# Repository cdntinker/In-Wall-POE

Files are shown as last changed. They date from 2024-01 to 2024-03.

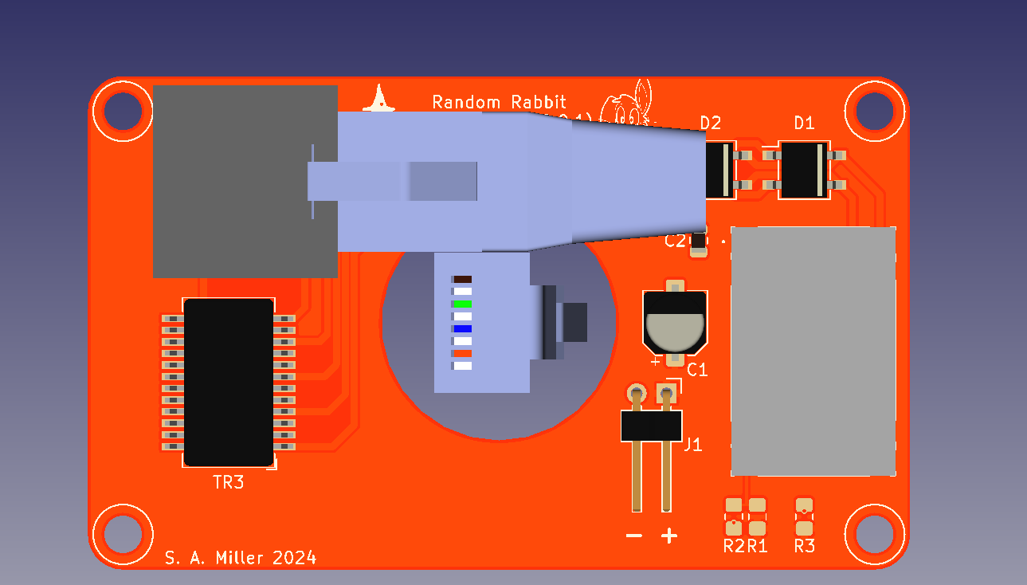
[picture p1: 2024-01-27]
3D/PoE top.png

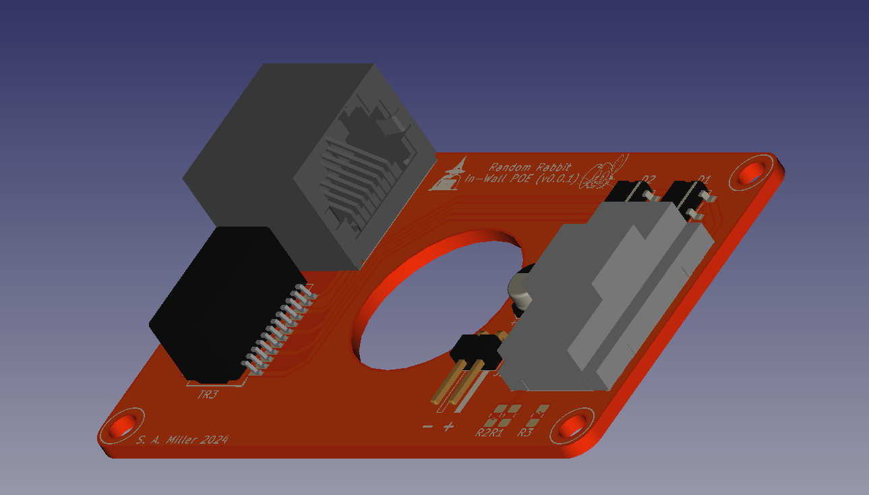
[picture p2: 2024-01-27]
3D/PoE.png

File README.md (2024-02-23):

Designed to fit inside of Wiremold surface mount boxes.

Inspired by the EAP235-wall wireless access point which has pass-through PoE.  I have a little receiver for my weather station that connects to the network via WiFi & is powered by a USB charger.

Center hole, initially,  exists to make room for the Ethernet cable feeding the EAP235.  Of course, it can also allow for the cables to feed into the wall.

J1 supplies 5V output at up to 7W and can have a USB-A pigtail connected to feed devices outside the box.

The outline on layer User1 is the internals of a typical Wiremold surface box.

> [!NOTE]
> The outline on layer User2 in the board view is a fairly accurate representation of an Ethernet plug in position in the jack.
> 
> The outline on layer User3 is a fairly accurate representation of an Ethernet plug in the back of the EAP235.

> [!TIP]
> Actual board should fit in ANY North American box.

> [!TIP]
> The PoE module in use is available in 3v3, 5v0 and 12v versions.
> So, this board could also be used to supply those voltages.

> [!NOTE]
> See notations in the schematic and refer to the datasheet for information about resistors R1-R3.

2024/01/22: upgraded from the overkill Ethernet jack to a better fit plus magnetics...

2024/02/13: Assembled first board
* No smoke, but not producing output properly...
  * So far, suspect it needs more of a load.  Will test once I find a USB-A pigtail.
* Need to change footprint of L1 to something easier to hand-solder & move C1 a little to the left to make assembly easier.

2024/02/15: Tested successfully
* Definitely needs minimum load.
  * Added 2x 470 ohm resistors in parallel at R3 (Now Rl1 & Rl2)
* ~~Does not seem to reliably keep voltage under much load.~~
  * ~~Possibly because of knock-off module?  Must get Silvertel modules & test...~~
* Modified L1 footprint, moved C1 & added an extra load resistor footprint.  All to ease assembly.

2024/02/22: Tested with actual Silvertel module AND no longer trust Chinese USB testers
* Received Silvertel module from Mouser & assembled another board.
  * EXACTLY the same results.
* **THEN**, Just for giggles, actually measured the output with my regular meter (Uni-T UT61e)
  * Well...  That's interesting.  UT61e says the output is a nice stable 5V (give or take ~0.03V)
  * Yet the load tester AND an inline USB tester both show severe voltage drop as current goes up.

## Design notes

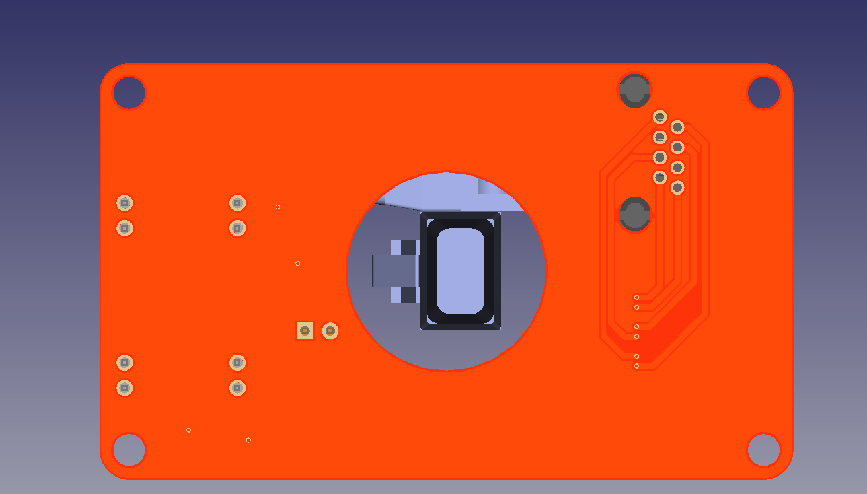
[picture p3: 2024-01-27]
3D/PoE bottom.png

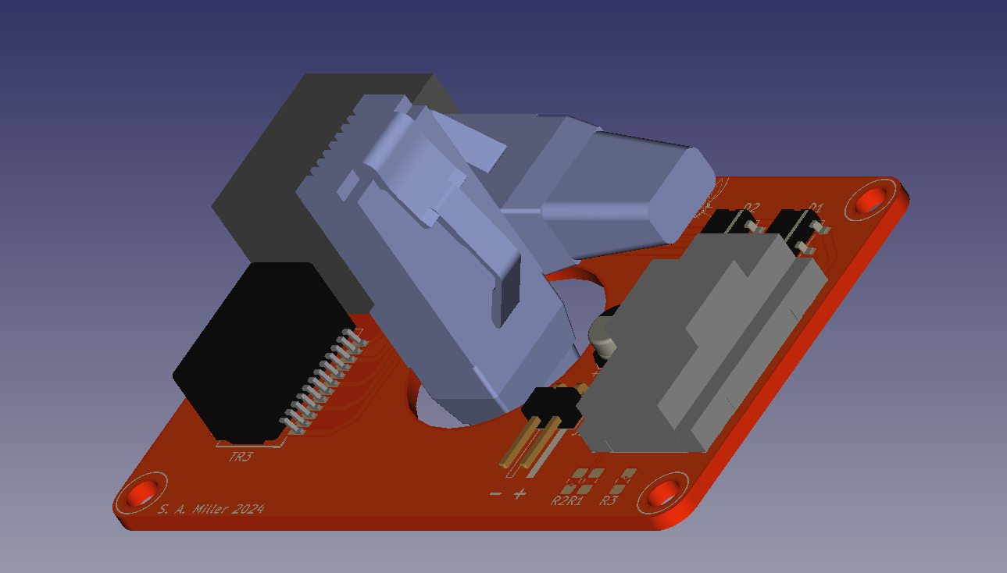
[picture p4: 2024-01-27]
3D/PoE Connected + WAP.png

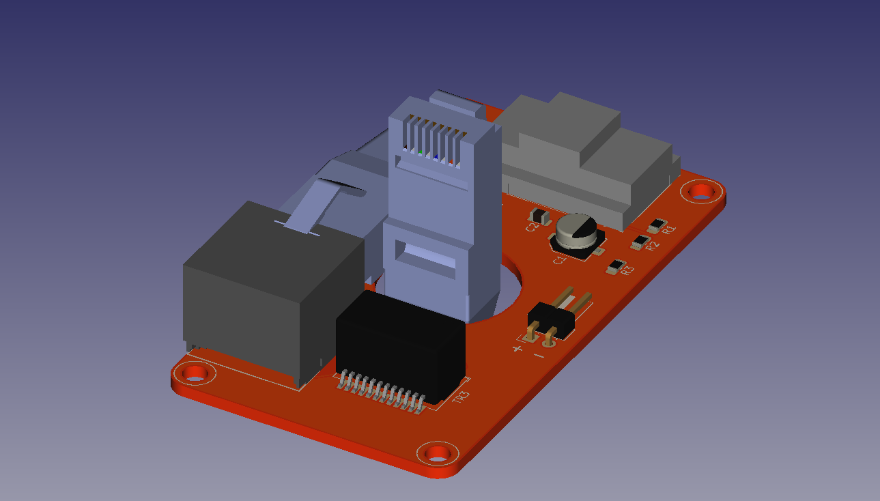
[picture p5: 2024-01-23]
3D/In Use.png

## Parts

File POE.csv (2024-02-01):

Component Count: | 16
Ref | Qnty | Cmp name | Value | LCSC | DigiKey | Footprint | Description
C1, | 1 | C_Polarized | 100uf | C7442639 |  | Capacitor_SMD:CP_Elec_6.3x5.4 | Polarized capacitor
C2, C3, | 2 | C | 10uf | C15850 |  | Capacitor_SMD:C_0805_2012Metric | Unpolarized capacitor
D1, D2, | 2 | MB4S | MB4S | C20612967 |  | Package_TO_SOT_SMD:TO-269AA | Miniature Glass Passivated Single-Phase Surface Mount Bridge Rectifiers, 280V Vrms, 0.5A If, TO-269AA
D3, | 1 | Z1SMAxxx | SMAJ58A | C280379 |  | Diode_SMD:D_SMA | 1000mW Zener Diode, SMA(DO-214AC)
D4, | 1 | LED | LED |  |  | LED_SMD:LED_0805_2012Metric | Light emitting diode
J1, | 1 | RC01374 | RC01374 | C385834 |  | tightstuff:RC01374
J2, | 1 | Conn_01x02_Male | Conn_01x02_Male |  |  | Connector_PinHeader_2.54mm:PinHeader_1x02_P2.54mm_Horizontal | Generic connector, single row, 01x02, script generated (kicad-library-utils/schlib/autogen/connector/)
L1, | 1 | L_Iron | fnr3015s1r | C167746 |  | tightstuff:fnr3015s | Inductor with iron core
MOD-1, | 1 | Ag9912LP | Ag9905LP | C5380108 |  | Tinker:Ag9912LP | Power over Ethernet - PoE IEEE802.3af PD module. 12V 10W low profile
R1, R2, R4, | 3 | R | ? |  |  | Resistor_SMD:R_0805_2012Metric_Pad1.20x1.40mm_HandSolder | Resistor
R3, | 1 | R | Rmin |  |  | Resistor_SMD:R_0805_2012Metric_Pad1.20x1.40mm_HandSolder | Resistor
TR3, | 1 | TG111-MSC13LF | SET2401ST | C7603464 |  | tightstuff:Eth_Magnetics (1.0) | Single Port Gigabit Ethernet Transformers

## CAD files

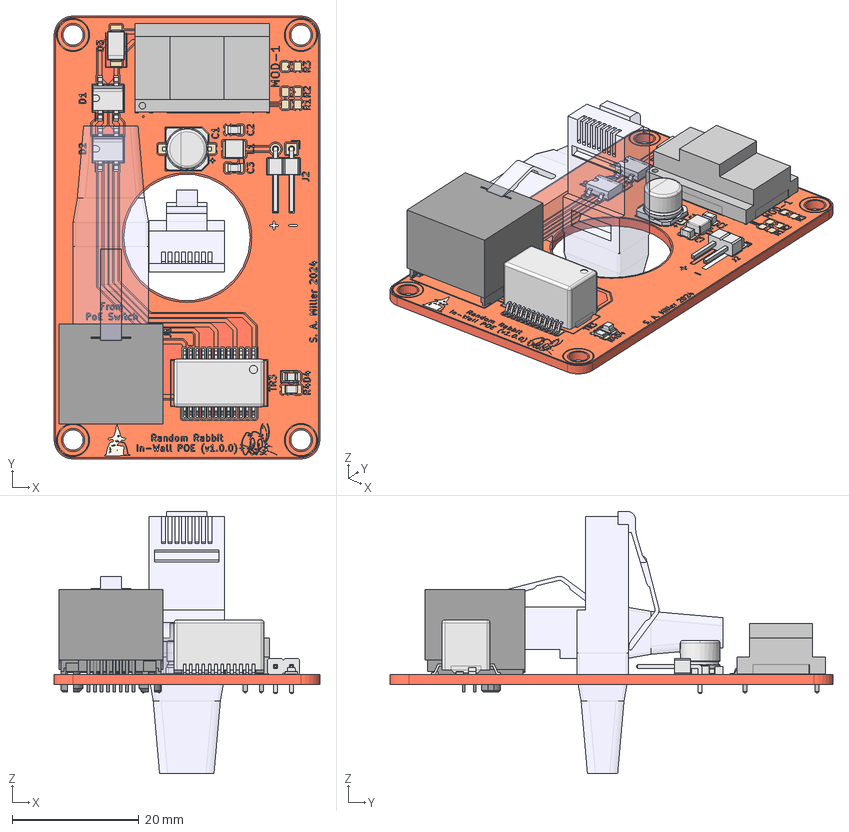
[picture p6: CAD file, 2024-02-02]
3D/PoE.FCStd
42.0 x 70.0 x 41.4 mm
Ethernet Male (in)
Ethernet Male
Pcb_5b5d001
topPads_5b5d001
topTracks_5b5d001
topZones_5b5d001
botPads_5b5d001
botTracks_5b5d001
botZones_5b5d001
topSilks_8e019
J1_RC01374_910414891cc3
D2_TO-269AA_a9b336d096a008 x 2
J2_PinHeader_1x02_P254mm_Horizontal_e8eeef0b0424
C1_CP_Elec_63x54_8ff1b6274a91
R4_R_0805_2012Metric_b68a1f3f8587
D3_D_SMA_5c7a696e1d8e001
MOD-1_Pocket_6c58673b8a2c001
C3_C_0805_2012Metric_1d8ab9cbe80f x 2
Transformer_Ethernet_HALO_TG111-MSC026
Transformer_Ethernet_HALO_TG111-MSC027
Transformer_Ethernet_HALO_TG111-MSC028
Transformer_Ethernet_HALO_TG111-MSC029
Transformer_Ethernet_HALO_TG111-MSC030
Transformer_Ethernet_HALO_TG111-MSC031
Transformer_Ethernet_HALO_TG111-MSC032
Transformer_Ethernet_HALO_TG111-MSC033
Transformer_Ethernet_HALO_TG111-MSC034
Transformer_Ethernet_HALO_TG111-MSC035
Transformer_Ethernet_HALO_TG111-MSC036
Transformer_Ethernet_HALO_TG111-MSC037
Transformer_Ethernet_HALO_TG111-MSC038
D4_LED_0805_2012Metric_7e3a714fea2e
L1_L_Wuerth_MAPI_3015_82f39c7c552b

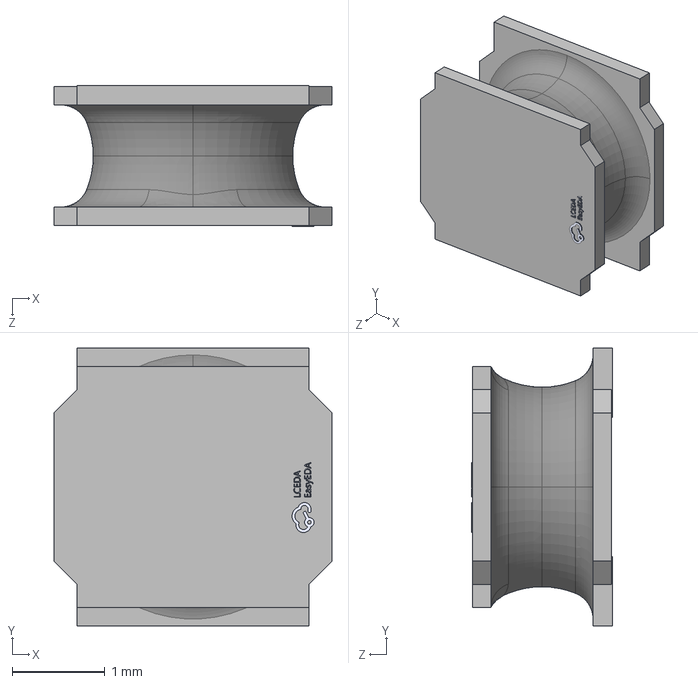
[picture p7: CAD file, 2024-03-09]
KiCAD Customs/3D/IND-SMD_L3.0-W3.0-H1.5_FNR30XXS.step
3.00 x 3.00 x 1.52 mm

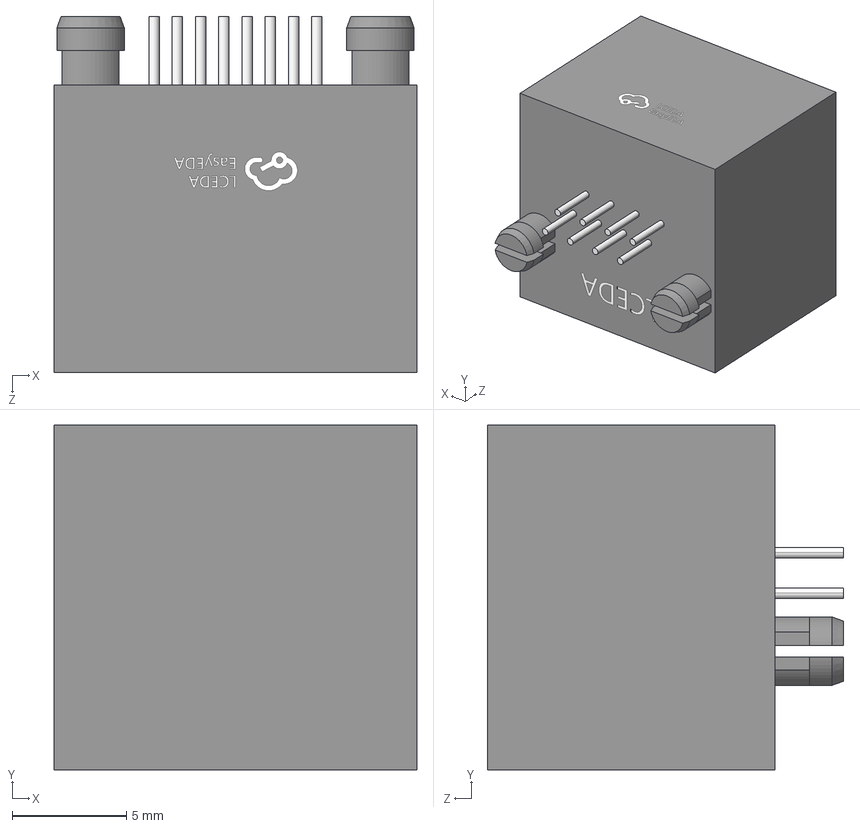
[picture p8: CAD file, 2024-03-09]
KiCAD Customs/3D/RJ45-TH_L15.9-W15.1-H12.6.step
15.9 x 15.1 x 15.6 mm

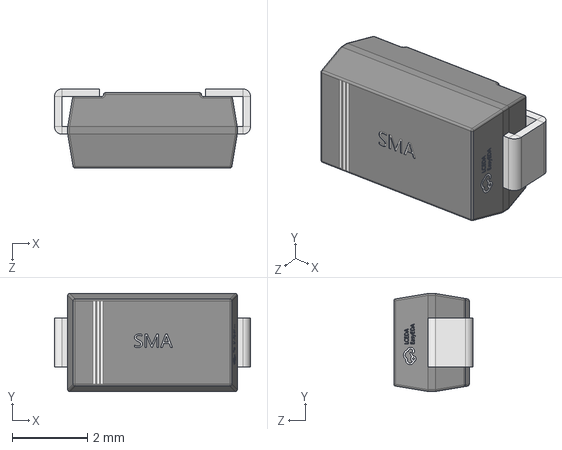
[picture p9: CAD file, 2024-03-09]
KiCAD Customs/3D/SMA_L4.4-W2.8-LS5.4-RD.step
5.20 x 2.60 x 2.10 mm

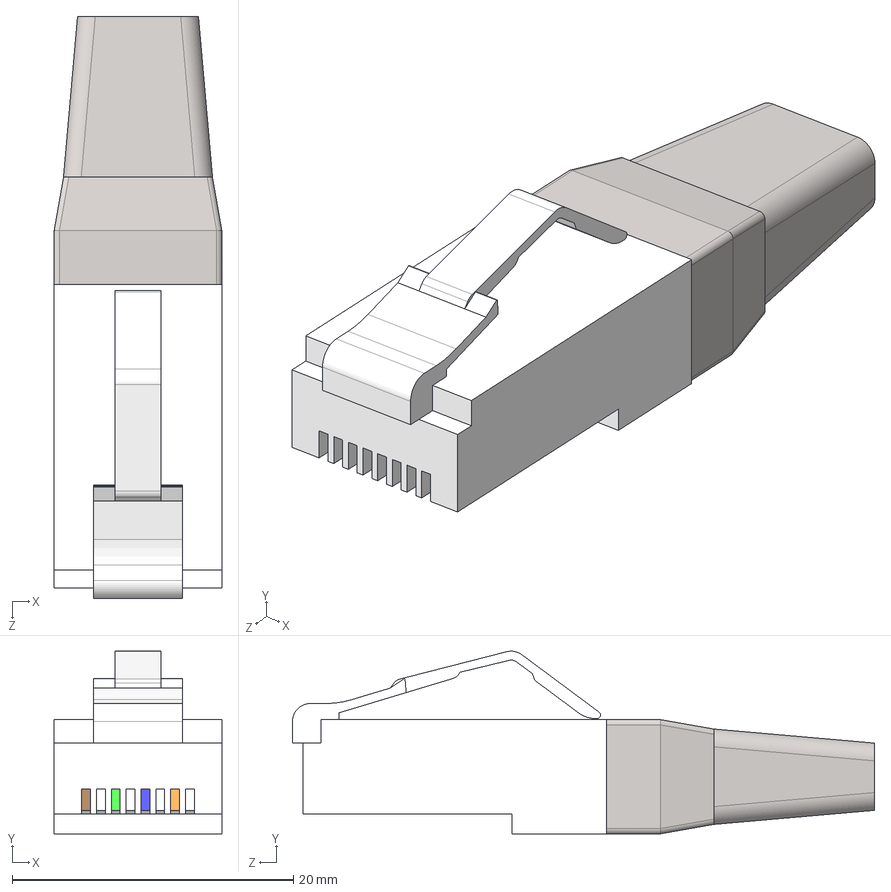
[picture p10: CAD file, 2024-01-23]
KiCAD Customs/3D/Ethernet Male.STEP
11.9 x 13.0 x 41.4 mm

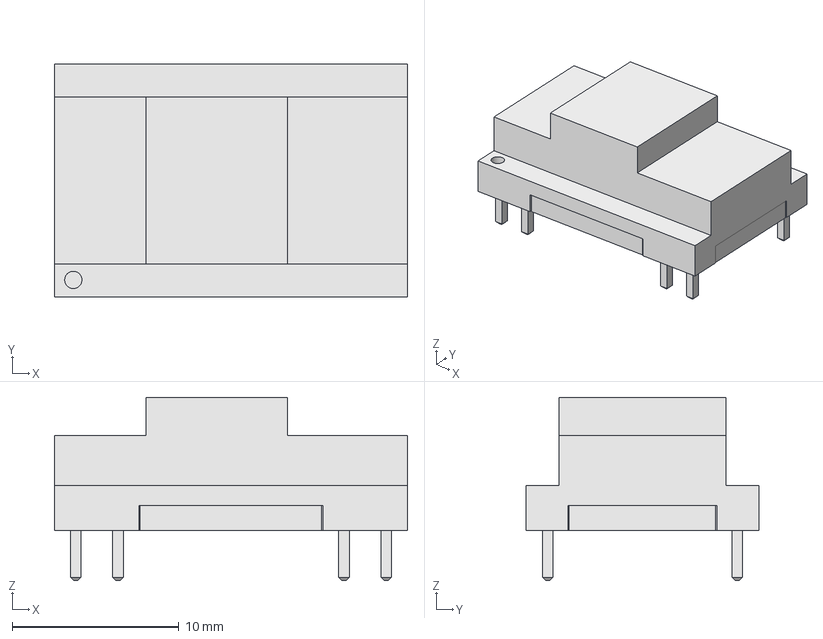
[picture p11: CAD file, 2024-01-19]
KiCAD Customs/3D/Ag9900LP.step
21.2 x 14.0 x 11.0 mm

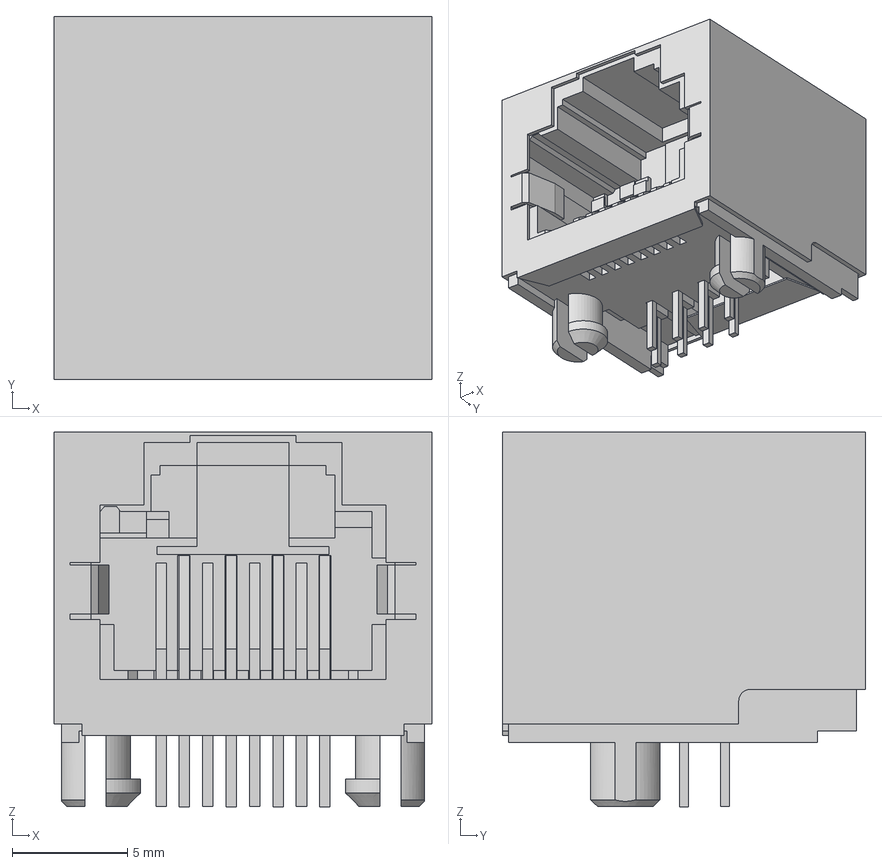
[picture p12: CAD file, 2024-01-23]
KiCAD Customs/3D/RC01374.step
16.4 x 15.8 x 16.3 mm

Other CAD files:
3D/POE-B_Silkscreen.dxf
3D/POE-F_Silkscreen.dxf

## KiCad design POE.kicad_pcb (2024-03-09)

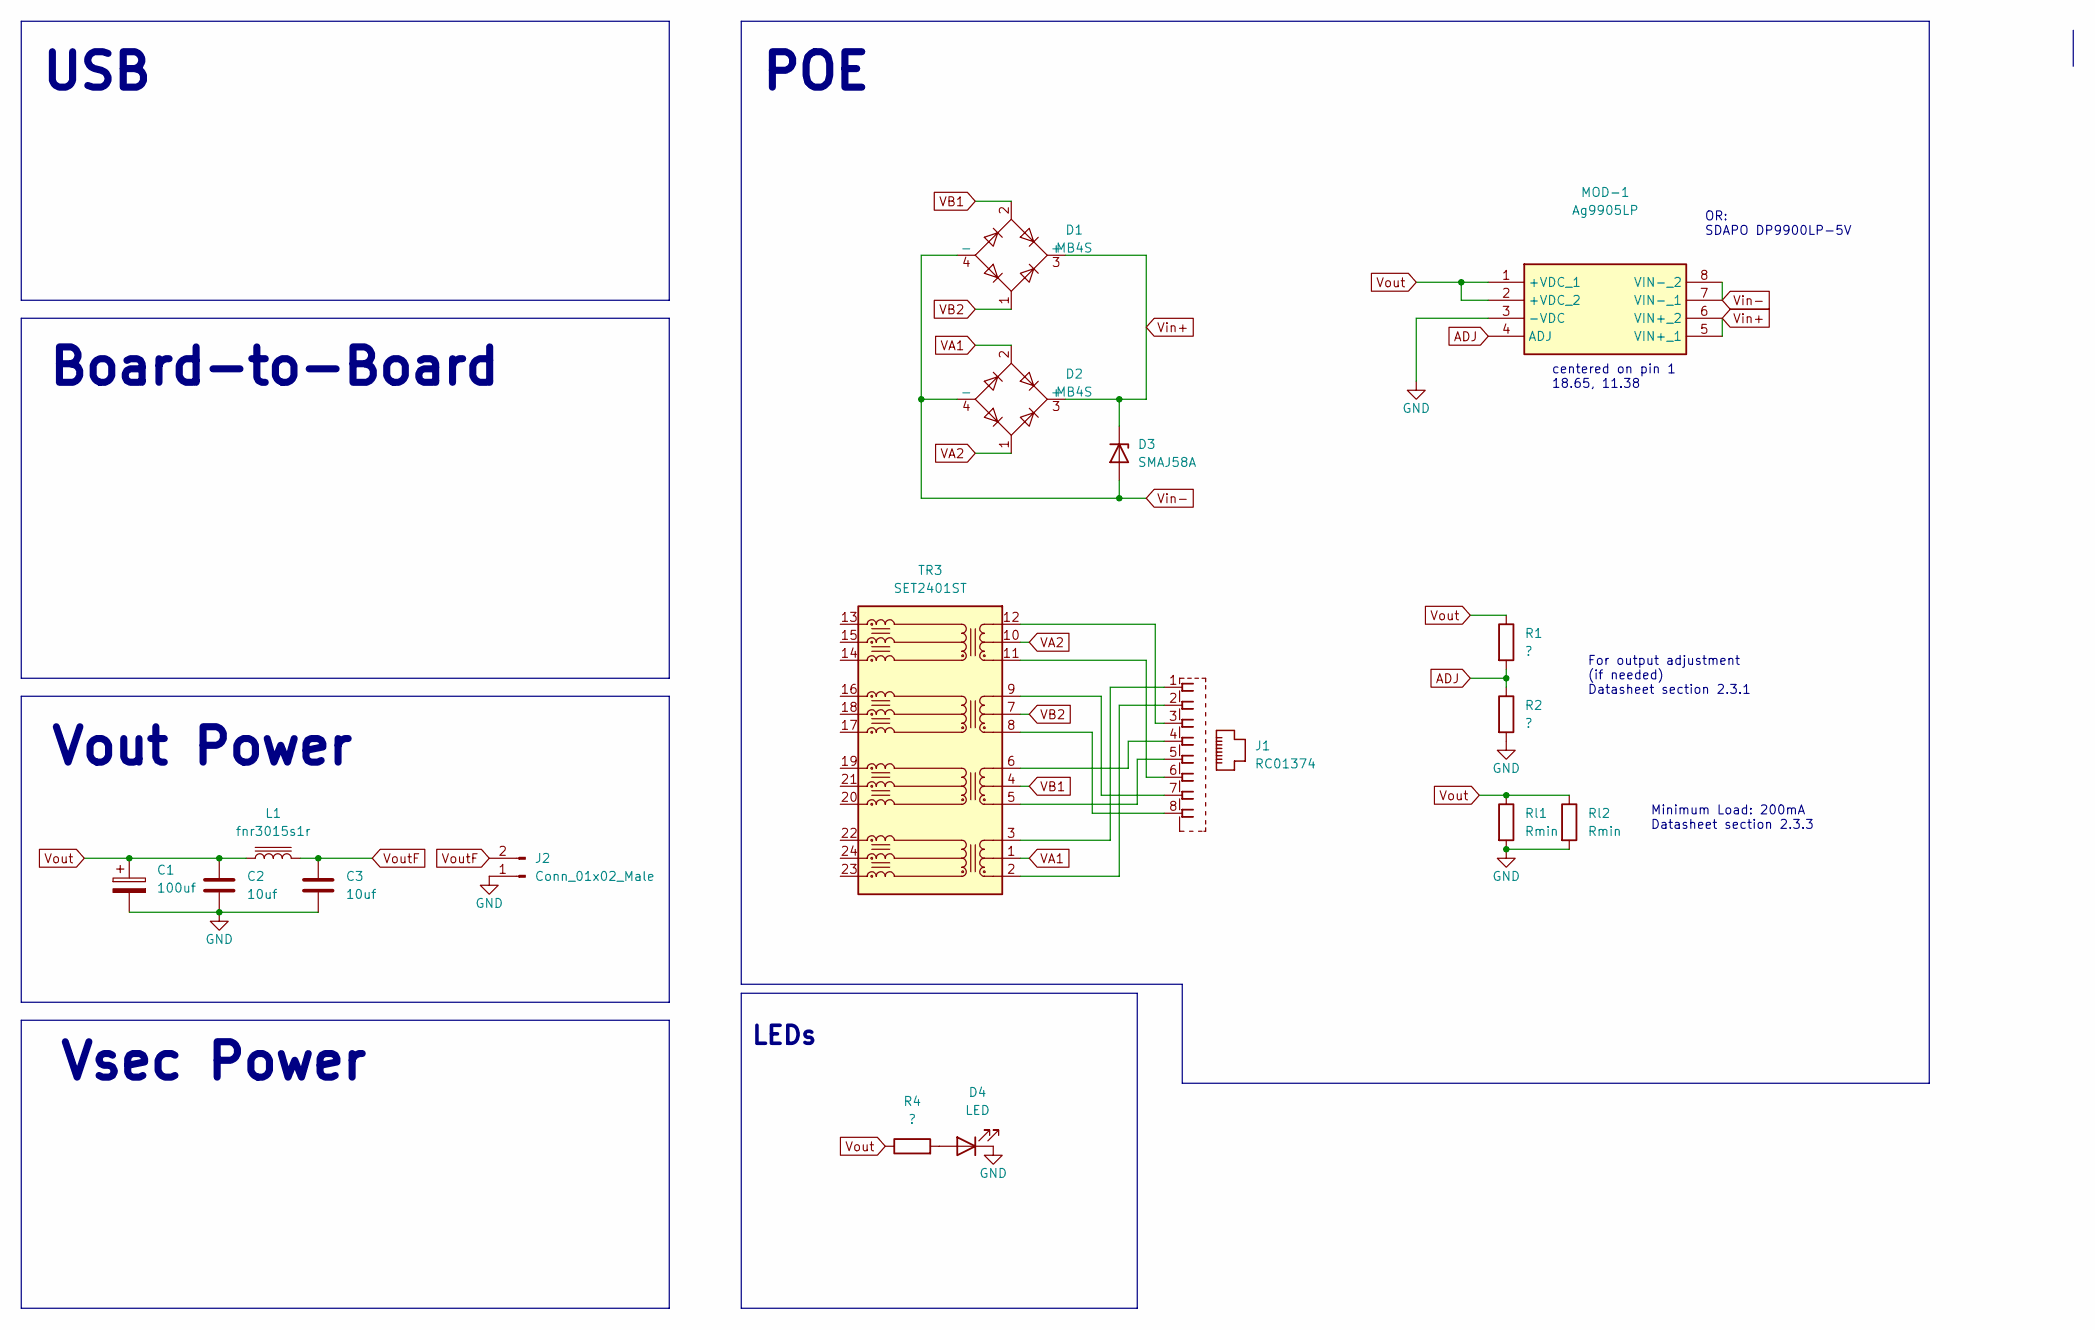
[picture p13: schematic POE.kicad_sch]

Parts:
C1: 100uf; CP_Elec_6.3x5.4; LCSC C7442639
C2, C3: 10uf; C_0805_2012Metric; LCSC C15850
D1, D2: MB4S; TO-269AA; LCSC C20612967
D3: SMAJ58A; D_SMA; LCSC C280379
D4: LED; LED_0805_2012Metric
J1: RC01374; LCSC C385834
J2: Conn_01x02_Male; PinHeader_1x02_P2.54mm_Horizontal
L1: fnr3015s1r; fnr3015s; LCSC C167746
MOD-1: Ag9905LP; Ag9912LP; Manufacturer_Part_Number Ag9905LP; LCSC C5380108
R1, R2, R4: ?; R_0805_2012Metric_Pad1.20x1.40mm_HandSolder
Rl1, Rl2: Rmin; R_0805_2012Metric_Pad1.20x1.40mm_HandSolder
TR3: SET2401ST; Eth_Magnetics (1.0); LCSC C7603464

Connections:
ADJ: MOD-1.4 (ADJ), R1.2, R2.1
GND: C1.2, C2.2, C3.2, D4.1 (K), J2.1, MOD-1.3 (-VDC), R2.2, Rl1.2, Rl2.2
unnamed: D4.2 (A), R4.2
unnamed: J1.1, TR3.3 (TD1-)
unnamed: J1.2, TR3.2 (TD1+)
unnamed: J1.3, TR3.12 (TD4-)
unnamed: J1.4, TR3.6 (TD2-)
unnamed: J1.5, TR3.5 (TD2+)
unnamed: J1.6, TR3.11 (TD4+)
unnamed: J1.7, TR3.9 (TD3-)
unnamed: J1.8, TR3.8 (TD3+)
VA1: D2.2, TR3.1 (TCT1)
VA2: D2.1, TR3.10 (TCT4)
VB1: D1.2, TR3.4 (TCT2)
VB2: D1.1, TR3.7 (TCT3)
Vin+: D1.3 (+), D2.3 (+), D3.1 (K), MOD-1.5 (VIN+_1), MOD-1.6 (VIN+_2)
Vin-: D1.4 (-), D2.4 (-), D3.2 (A), MOD-1.7 (VIN-_1), MOD-1.8 (VIN-_2)
Vout: C1.1, C2.1, L1.1, MOD-1.1 (+VDC_1), MOD-1.2 (+VDC_2), R1.1, R4.1, Rl1.1, Rl2.1
VoutF: C3.1, J2.2, L1.2

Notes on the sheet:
Vsec Power
Vout Power
OR: SDAPO DP9900LP-5V
USB
centered on pin 1 18.65, 11.38
Board-to-Board
For output adjustment (if needed) Datasheet section 2.3.1
POE
Minimum Load: 200mA Datasheet section 2.3.3
LEDs

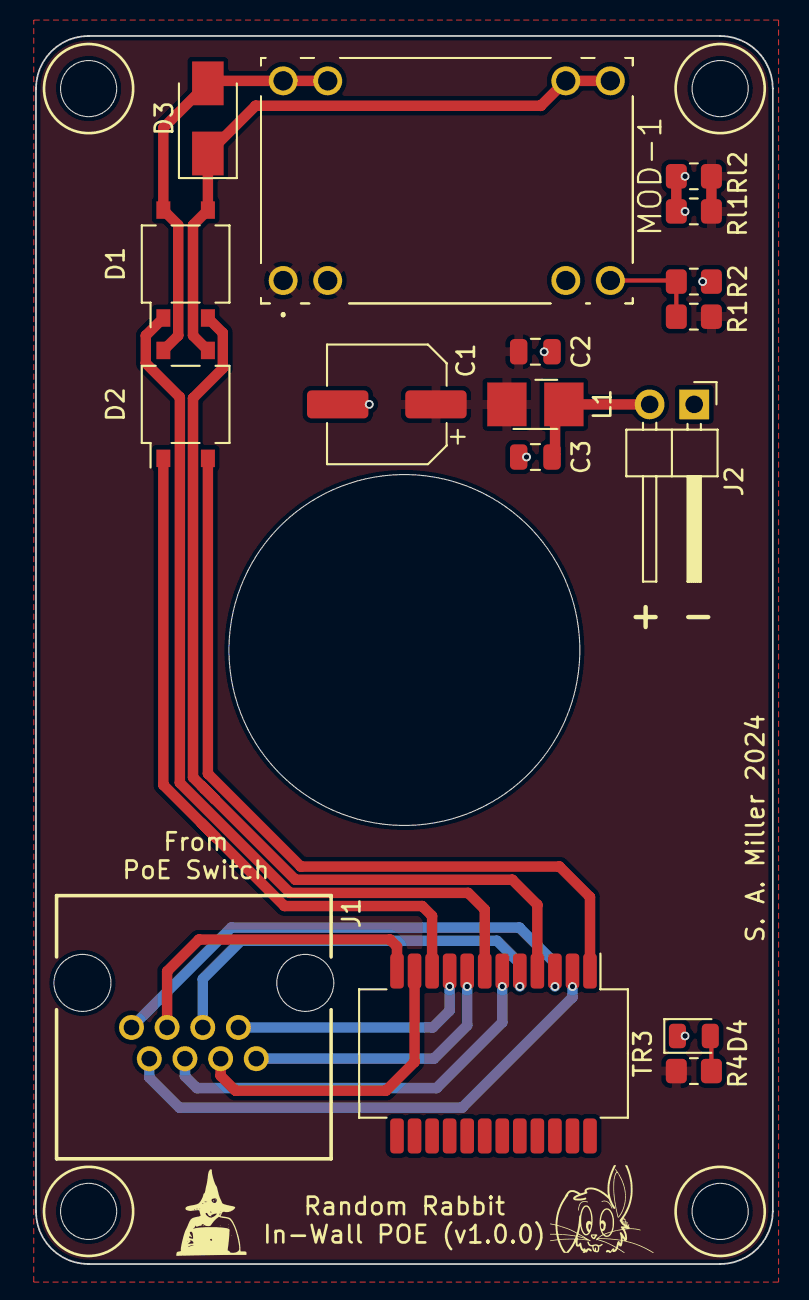
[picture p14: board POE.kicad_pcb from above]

Board: 2 copper layers, 42.0 x 70.0 mm, 17 parts (0 on the bottom side), 19 nets.

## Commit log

2024-01-19 Some tweaking and explanation(s)
    [POE.kicad_pcb]
2024-01-19 Added adjustment & minLoad resistors
    [POE.kicad_pcb, POE.kicad_sch]
2024-01-23 upgraded from the overkill Ethernet jack to a better fit plus magnetics
    [POE.kicad_pcb, POE.kicad_sch, RC01374.step]
2024-01-23 Addes a 3D nodel & renders
    [Ethernet Male.STEP, POE-B_Silkscreen.dxf, POE-F_Silkscreen.dxf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]
2024-01-23 trying to fix gitignore
    [PoE.FCStd]
2024-01-27 Some layout rework...
    [POE-F_Silkscreen.dxf, POE.kicad_pcb, POE.kicad_sch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]
2024-02-01 Improved Vout filtering
    [POE-F_Silkscreen.dxf, POE.kicad_pcb, POE.kicad_sch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]
2024-02-01 foorprint improvements & parts selections...
    [POE.kicad_pcb, POE.kicad_sch]
2024-02-01 Prepping for possible first build...
    [POE.kicad_pcb, POE.kicad_sch]
2024-02-01 gerbers produced, boards & parts ordered... (w/slow-boat shipping...)
    [POE-B_Adhesive.gbr, POE-B_Cu.gbr, POE-B_Mask.gbr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]
2024-02-14 Thoughts after first assembly
2024-02-15 Post-test thoughts & adjustments.
    [POE.kicad_pcb, POE.kicad_sch]
2024-03-09 bye bye bloody wrl files
    [AG9912-MTB.stp, AG9912M.stp, ARJM11D7114ABEW2.step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]
